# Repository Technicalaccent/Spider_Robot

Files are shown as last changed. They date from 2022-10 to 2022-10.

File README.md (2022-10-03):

# Spider Robot Master

What Is a "Spider Robot?"

	As its name defines it, our robot is a basic representation of the sipder movements but it will not perform exactly the same body moves since we are using only four legs instead of eight legs.

	Named also a Quadrupedrobot since it has four legs and make its movements using these legs, the movment of each leg is related to the other legs in order to identify the roboty body postion and also to control the robot body balance.

	Legged robots handle terrain better than their wheeled counterparts and move in varied and animalistic ways. However, this makes legged robots more complicated, and less accessible to many makers. and also the making cost and the high depenses that a maker should spend in order to create a full body quadruped since it is based on servo motors or stepper motors and both are more expensive than DC motors that could be used in wheeled robots.

Advantages

	You will find quadrupeds abundant in nature, because four legs allow for passive stability, or the ability to stay standing without actively adjusting position. The same is true of robots. A four-legged robot is cheaper and simpler than a robot with more legs, yet it can still achieve stability.

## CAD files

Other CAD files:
SpiderRobot master/3D parts/spider_robot.skp

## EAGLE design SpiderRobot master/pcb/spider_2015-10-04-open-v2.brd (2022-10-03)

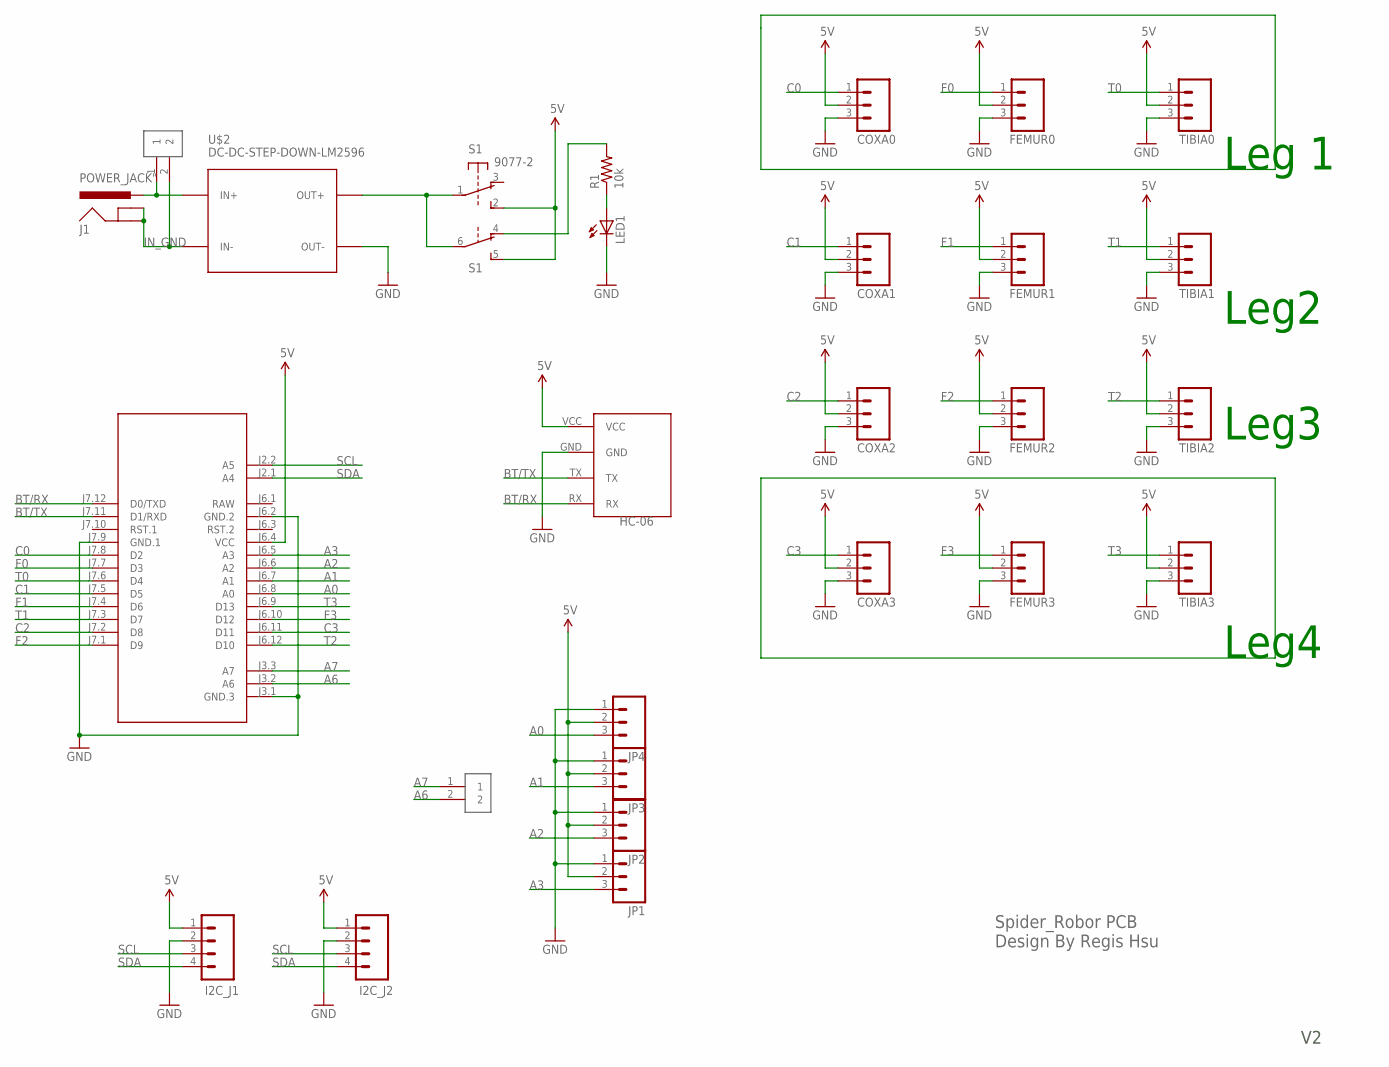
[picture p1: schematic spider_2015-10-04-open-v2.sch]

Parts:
COXA0, COXA1, COXA2, COXA3: M03PTH; 1X03
FEMUR0, FEMUR1, FEMUR2, FEMUR3: M03PTH; 1X03
HC-06: BLUETOOTH_BOARDSTANDING; BT_BOARD_FOOTPRINT_STANDING
I2C_J1, I2C_J2: 1X04_HEADER"; 1X04_HEADER
J1: POWER_JACK"; POWER_JACK
JP1, JP2, JP3, JP4: M03PTH; 1X03
LED1: LED3MM; LED
M1: ARDUINO-PRO-MINI-5.0V; ARDUINO-PRO-MINI
R1: 10k; AXIAL-0.4
S1: 9077-2
TIBIA0, TIBIA1, TIBIA2, TIBIA3: M03PTH; 1X03
U$1, U$3: 1X02_HEADER
U$2: DC-DC-STEP-DOWN-LM2596

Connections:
5V: COXA0.2, COXA1.2, COXA2.2, COXA3.2, FEMUR0.2, FEMUR1.2, FEMUR2.2, FEMUR3.2, HC-06.VCC, I2C_J1.1, I2C_J2.1, JP1.2, JP2.2, JP3.2, JP4.2, M1.J6.4 (VCC), S1.2 (S), S1.5 (S), TIBIA0.2, TIBIA1.2, TIBIA2.2, TIBIA3.2
A0: JP4.3, M1.J6.8 (A0)
A1: JP3.3, M1.J6.7 (A1)
A2: JP2.3, M1.J6.6 (A2)
A3: JP1.3, M1.J6.5 (A3)
A6: M1.J3.2 (A6), U$1.2
A7: M1.J3.3 (A7), U$1.1
BT/RX: HC-06.RX, M1.J7.12 (D0/TXD)
BT/TX: HC-06.TX, M1.J7.11 (D1/RXD)
C0: COXA0.1, M1.J7.8 (D2)
C1: COXA1.1, M1.J7.5 (D5)
C2: COXA2.1, M1.J7.2 (D8)
C3: COXA3.1, M1.J6.11 (D11)
F0: FEMUR0.1, M1.J7.7 (D3)
F1: FEMUR1.1, M1.J7.4 (D6)
F2: FEMUR2.1, M1.J7.1 (D9)
F3: FEMUR3.1, M1.J6.10 (D12)
GND: COXA0.3, COXA1.3, COXA2.3, COXA3.3, FEMUR0.3, FEMUR1.3, FEMUR2.3, FEMUR3.3, HC-06.GND, I2C_J1.2, I2C_J2.2, JP1.1, JP2.1, JP3.1, JP4.1, LED1.K (C), M1.J3.1 (GND.3), M1.J6.2 (GND.2), M1.J7.9 (GND.1), TIBIA0.3, TIBIA1.3, TIBIA2.3, TIBIA3.3, U$2.OUT-
IN_GND: J1.GND, J1.GNDBREAK, U$2.IN-, U$3.2
unnamed: J1.PWR, U$2.IN+, U$3.1
unnamed: S1.1, S1.6, U$2.OUT+
unnamed: R1.P$2 (2), S1.4 (O)
unnamed: LED1.A, R1.P$1 (1)
RAW: M1.J6.1 (RAW)
SCL: I2C_J1.3, I2C_J2.3, M1.J2.2 (A5)
SDA: I2C_J1.4, I2C_J2.4, M1.J2.1 (A4)
T0: M1.J7.6 (D4), TIBIA0.1
T1: M1.J7.3 (D7), TIBIA1.1
T2: M1.J6.12 (D10), TIBIA2.1
T3: M1.J6.9 (D13), TIBIA3.1

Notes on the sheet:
Spider_Robor PCB Design By Regis Hsu
Leg 1
Leg4
Leg3
Leg2

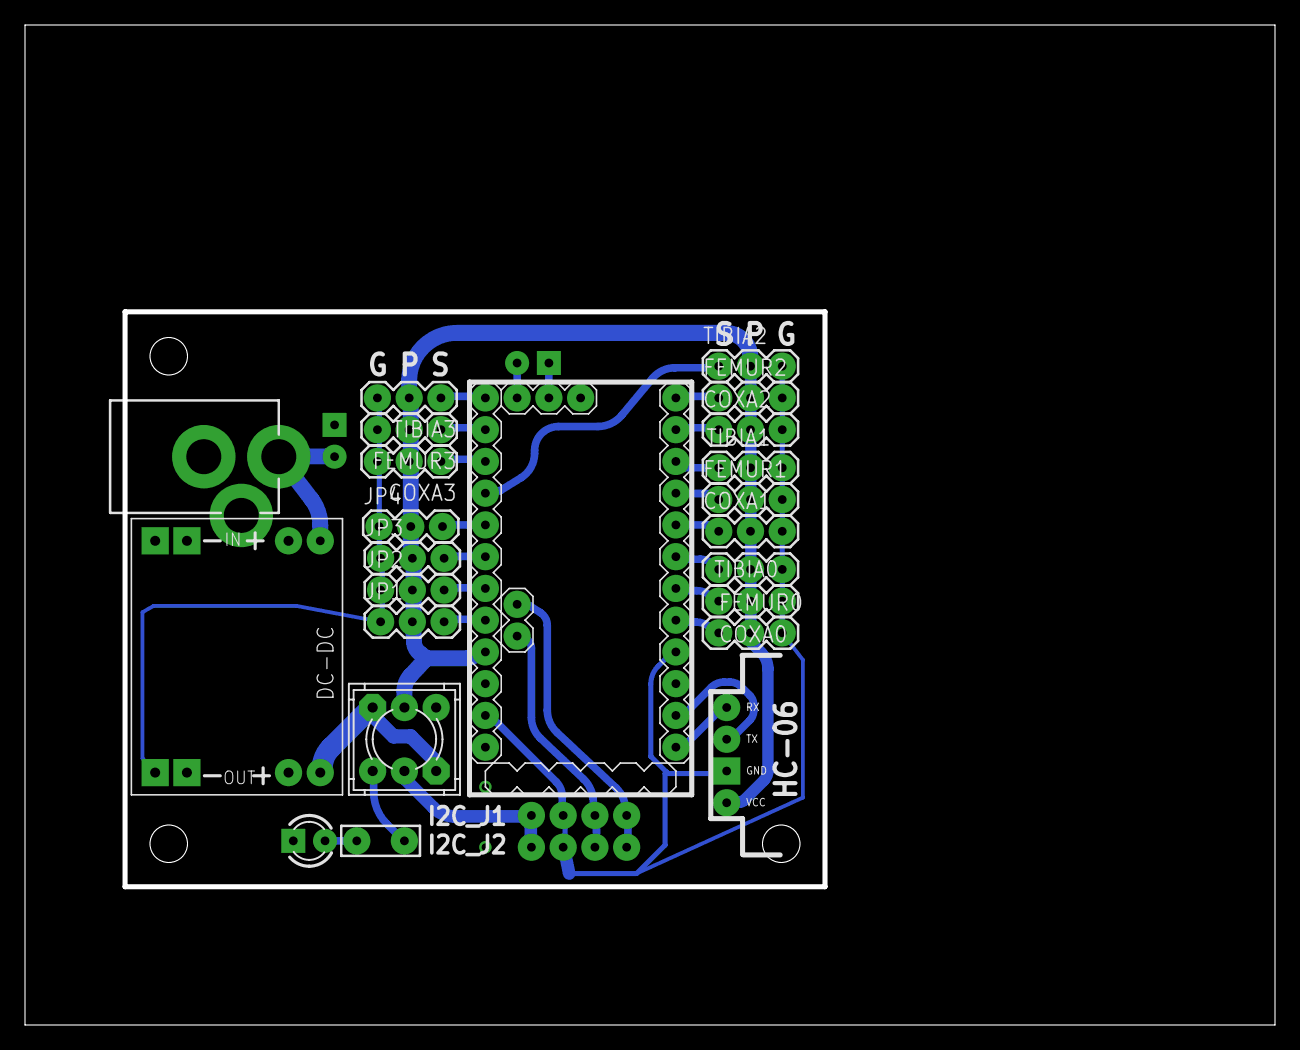
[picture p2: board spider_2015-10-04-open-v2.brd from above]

Board: 2 copper layers, 100.0 x 80.0 mm, 27 parts (0 on the bottom side), 29 nets.

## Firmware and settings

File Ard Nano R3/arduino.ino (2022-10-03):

/************************************************************************************************************************************************************************                                              

Spider Robot

***********************************************************************************************************************************************************************/

#include <Servo.h>    //to define and control servos
#include <FlexiTimer2.h>//to set a timer to manage all servos
#include <Wire.h>
#include <Adafruit_SSD1306.h>
#include <Adafruit_GFX.h>

// OLED display TWI address
#define OLED_ADDR   0x3C
Adafruit_SSD1306 display(-1);
/* Servos --------------------------------------------------------------------*/
//define 12 servos for 4 legs
Servo servo[4][3];
//define servos' ports
const int servo_pin[4][3] = { {11, 12, 13}, {2, 4, 7}, {14, 15, 16},{8, 9, 10} };/* Size of the robot ---------------------------------------------------------*/
const float length_a = 50;
const float length_b = 77.1;
const float length_c = 27.5;
const float length_side = 71;
const float z_absolute = -28;
/* Constants for movement ----------------------------------------------------*/
const float z_default = -50, z_up = -30, z_boot = z_absolute;
const float x_default = 62, x_offset = 0;
const float y_start = 0, y_step = 40;
const float y_default = x_default;
/* variables for movement ----------------------------------------------------*/
volatile float site_now[4][3];    //real-time coordinates of the end of each leg
volatile float site_expect[4][3]; //expected coordinates of the end of each leg
float temp_speed[4][3];   //each axis' speed, needs to be recalculated before each movement
float move_speed;     //movement speed
float speed_multiple = 1; //movement speed multiple
const float spot_turn_speed = 4;
const float leg_move_speed = 8;
const float body_move_speed = 3;
const float stand_seat_speed = 1;
volatile int rest_counter;      //+1/0.02s, for automatic rest
//functions' parameter
const float KEEP = 255;
//define PI for calculation
const float pi = 3.1415926;
/* Constants for turn --------------------------------------------------------*/
//temp length
const float temp_a = sqrt(pow(2 * x_default + length_side, 2) + pow(y_step, 2));
const float temp_b = 2 * (y_start + y_step) + length_side;
const float temp_c = sqrt(pow(2 * x_default + length_side, 2) + pow(2 * y_start + y_step + length_side, 2));
const float temp_alpha = acos((pow(temp_a, 2) + pow(temp_b, 2) - pow(temp_c, 2)) / 2 / temp_a / temp_b);
//site for turn
const float turn_x1 = (temp_a - length_side) / 2;
const float turn_y1 = y_start + y_step / 2;
const float turn_x0 = turn_x1 - temp_b * cos(temp_alpha);
const float turn_y0 = temp_b * sin(temp_alpha) - turn_y1 - length_side;

const int lightR=3;
const int lightG=5;
const int lightB=6;

int LedR=0;
int LedG=0;
int LedB=0;

char SerialData;                                    // Use this variable to read each caractere received through serial port
String data="";
void setup() 
{
  Serial.begin(9600);
  display.begin(SSD1306_SWITCHCAPVCC, OLED_ADDR);
  display.clearDisplay();
  display.display();
  delay(10000);
  set_site(0, x_default - x_offset, y_start + y_step, z_boot);
  set_site(1, x_default - x_offset, y_start + y_step, z_boot);
  set_site(2, x_default + x_offset, y_start, z_boot);
  set_site(3, x_default + x_offset, y_start, z_boot);
  for (int i = 0; i < 4; i++)
  {
    for (int j = 0; j < 3; j++)
    {
      site_now[i][j] = site_expect[i][j];
    }
  }
  //start servo service
  FlexiTimer2::set(20, servo_service);
  FlexiTimer2::start();
  //initialize servos
  servo_attach();
  stand();
//  delay(3000);
//  sit();
//  delay(3000);
//  stand();
//  delay(3000);
  happy();
  delay (random (500, 1000));
  cierra();
  delay (150);
  enfado();
  delay (random (1000, 3000));
  cierra();
  delay (150);
  entorna();
  delay (random (1000, 3000));
  cierra();
  delay (150);
  enfado1();
  delay (random (1000, 3000));
  cierra();
  delay (150);
  triste();
  delay (random (1000, 3000));
  cierra();
  delay (150);
  abre();
  delay (random (500, 3000));
  cierra();
  delay (150);
  happy();
  delay (random (500, 1000));
}

void loop() 
{
  while(Serial.available())                   // While serial data are available we store it 
  {
    delay(10);
    SerialData=Serial.read();
    if(SerialData=='b')
    LedR=Serial.parseInt();
    else if(SerialData=='g')
    LedG=Serial.parseInt();
    else if(SerialData=='r')
    LedB=Serial.parseInt();
    else
    data+=SerialData;
  }
  if(data=="f")                                  // If the stored data is forward movement
  {
    cierra();
    delay (150);
    happy();
    step_forward(1);
  }

  if(data=="p")                                  // If the stored data is backward movement
  {
    cierra();
    delay (150);
    triste();
    step_back(1);
  }

  if(data=="l")                                  // If the stored data is to turn left the car 
  {
    cierra();
    delay (150);
    enfado1();
    turn_left(1);
  }

  if(data=="m")                                  // If the stored data is to turn right the car
  {
    cierra();
    delay (150);
    enfado();
    turn_right(5);
  }
  data="";
  analogWrite(lightR,LedR);
  analogWrite(lightG,LedG);
  analogWrite(lightB,LedB);
}
void servo_attach(void)
{
  for (int i = 0; i < 4; i++)
  {
    for (int j = 0; j < 3; j++)
    {
      servo[i][j].attach(servo_pin[i][j]);
      delay(100);
    }
  }
}

void servo_detach(void)
{
  for (int i = 0; i < 4; i++)
  {
    for (int j = 0; j < 3; j++)
    {
      servo[i][j].detach();
      delay(100);
    }
  }
}

void sit(void)
{
  move_speed = stand_seat_speed;
  for (int leg = 0; leg < 4; leg++)
  {
    set_site(leg, KEEP, KEEP, z_boot);
  }
  wait_all_reach();
}

/*
  - stand
  - blocking function
   ---------------------------------------------------------------------------*/
void stand(void)
{
  move_speed = stand_seat_speed;
  for (int leg = 0; leg < 4; leg++)
  {
    set_site(leg, KEEP, KEEP, z_default);
  }
  wait_all_reach();
}


/*
  - spot turn to left
  - blocking function
  - parameter step steps wanted to turn
   ---------------------------------------------------------------------------*/
void turn_left(unsigned int step)
{
  move_speed = spot_turn_speed;
  while (step-- > 0)
  {
    if (site_now[3][1] == y_start)
    {
      //leg 3&1 move
      set_site(3, x_default + x_offset, y_start, z_up);
      wait_all_reach();

      set_site(0, turn_x1 - x_offset, turn_y1, z_default);
      set_site(1, turn_x0 - x_offset, turn_y0, z_default);
      set_site(2, turn_x1 + x_offset, turn_y1, z_default);
      set_site(3, turn_x0 + x_offset, turn_y0, z_up);
      wait_all_reach();

      set_site(3, turn_x0 + x_offset, turn_y0, z_default);
      wait_all_reach();

      set_site(0, turn_x1 + x_offset, turn_y1, z_default);
      set_site(1, turn_x0 + x_offset, turn_y0, z_default);
      set_site(2, turn_x1 - x_offset, turn_y1, z_default);
      set_site(3, turn_x0 - x_offset, turn_y0, z_default);
      wait_all_reach();

      set_site(1, turn_x0 + x_offset, turn_y0, z_up);
      wait_all_reach();

      set_site(0, x_default + x_offset, y_start, z_default);
      set_site(1, x_default + x_offset, y_start, z_up);
      set_site(2, x_default - x_offset, y_start + y_step, z_default);
      set_site(3, x_default - x_offset, y_start + y_step, z_default);
      wait_all_reach();

      set_site(1, x_default + x_offset, y_start, z_default);
      wait_all_reach();
    }
    else
    {
      //leg 0&2 move
      set_site(0, x_default + x_offset, y_start, z_up);
      wait_all_reach();

      set_site(0, turn_x0 + x_offset, turn_y0, z_up);
      set_site(1, turn_x1 + x_offset, turn_y1, z_default);
      set_site(2, turn_x0 - x_offset, turn_y0, z_default);
      set_site(3, turn_x1 - x_offset, turn_y1, z_default);
      wait_all_reach();

      set_site(0, turn_x0 + x_offset, turn_y0, z_default);
      wait_all_reach();

      set_site(0, turn_x0 - x_offset, turn_y0, z_default);
      set_site(1, turn_x1 - x_offset, turn_y1, z_default);
      set_site(2, turn_x0 + x_offset, turn_y0, z_default);
      set_site(3, turn_x1 + x_offset, turn_y1, z_default);
      wait_all_reach();

      set_site(2, turn_x0 + x_offset, turn_y0, z_up);
      wait_all_reach();

      set_site(0, x_default - x_offset, y_start + y_step, z_default);
      set_site(1, x_default - x_offset, y_start + y_step, z_default);
      set_site(2, x_default + x_offset, y_start, z_up);
      set_site(3, x_default + x_offset, y_start, z_default);
      wait_all_reach();

      set_site(2, x_default + x_offset, y_start, z_default);
      wait_all_reach();
    }
  }
}

/*
  - spot turn to right
  - blocking function
  - parameter step steps wanted to turn
   ---------------------------------------------------------------------------*/
void turn_right(unsigned int step)
{
  move_speed = spot_turn_speed;
  while (step-- > 0)
  {
    if (site_now[2][1] == y_start)
    {
      //leg 2&0 move
      set_site(2, x_default + x_offset, y_start, z_up);
      wait_all_reach();

      set_site(0, turn_x0 - x_offset, turn_y0, z_default);
      set_site(1, turn_x1 - x_offset, turn_y1, z_default);
      set_site(2, turn_x0 + x_offset, turn_y0, z_up);
      set_site(3, turn_x1 + x_offset, turn_y1, z_default);
      wait_all_reach();

      set_site(2, turn_x0 + x_offset, turn_y0, z_default);
      wait_all_reach();

      set_site(0, turn_x0 + x_offset, turn_y0, z_default);
      set_site(1, turn_x1 + x_offset, turn_y1, z_default);
      set_site(2, turn_x0 - x_offset, turn_y0, z_default);
      set_site(3, turn_x1 - x_offset, turn_y1, z_default);
      wait_all_reach();

      set_site(0, turn_x0 + x_offset, turn_y0, z_up);
      wait_all_reach();

      set_site(0, x_default + x_offset, y_start, z_up);
      set_site(1, x_default + x_offset, y_start, z_default);
      set_site(2, x_default - x_offset, y_start + y_step, z_default);
      set_site(3, x_default - x_offset, y_start + y_step, z_default);
      wait_all_reach();

      set_site(0, x_default + x_offset, y_start, z_default);
      wait_all_reach();
    }
    else
    {
      //leg 1&3 move
      set_site(1, x_default + x_offset, y_start, z_up);
      wait_all_reach();

      set_site(0, turn_x1 + x_offset, turn_y1, z_default);
      set_site(1, turn_x0 + x_offset, turn_y0, z_up);
      set_site(2, turn_x1 - x_offset, turn_y1, z_default);
      set_site(3, turn_x0 - x_offset, turn_y0, z_default);
      wait_all_reach();

      set_site(1, turn_x0 + x_offset, turn_y0, z_default);
      wait_all_reach();

      set_site(0, turn_x1 - x_offset, turn_y1, z_default);
      set_site(1, turn_x0 - x_offset, turn_y0, z_default);
      set_site(2, turn_x1 + x_offset, turn_y1, z_default);
      set_site(3, turn_x0 + x_offset, turn_y0, z_default);
      wait_all_reach();

      set_site(3, turn_x0 + x_offset, turn_y0, z_up);
      wait_all_reach();

      set_site(0, x_default - x_offset, y_start + y_step, z_default);
      set_site(1, x_default - x_offset, y_start + y_step, z_default);
      set_site(2, x_default + x_offset, y_start, z_default);
      set_site(3, x_default + x_offset, y_start, z_up);
      wait_all_reach();

      set_site(3, x_default + x_offset, y_start, z_default);
      wait_all_reach();
    }
  }
}

/*
  - go forward
  - blocking function
  - parameter step steps wanted to go
   ---------------------------------------------------------------------------*/
void step_forward(unsigned int step)
{
  move_speed = leg_move_speed;
  while (step-- > 0)
  {
    if (site_now[2][1] == y_start)
    {
      //leg 2&1 move
      set_site(2, x_default + x_offset, y_start, z_up);
      wait_all_reach();
      set_site(2, x_default + x_offset, y_start + 2 * y_step, z_up);
      wait_all_reach();
      set_site(2, x_default + x_offset, y_start + 2 * y_step, z_default);
      wait_all_reach();

      move_speed = body_move_speed;

      set_site(0, x_default + x_offset, y_start, z_default);
      set_site(1, x_default + x_offset, y_start + 2 * y_step, z_default);
      set_site(2, x_default - x_offset, y_start + y_step, z_default);
      set_site(3, x_default - x_offset, y_start + y_step, z_default);
      wait_all_reach();

      move_speed = leg_move_speed;

      set_site(1, x_default + x_offset, y_start + 2 * y_step, z_up);
      wait_all_reach();
      set_site(1, x_default + x_offset, y_start, z_up);
      wait_all_reach();
      set_site(1, x_default + x_offset, y_start, z_default);
      wait_all_reach();
    }
    else
    {
      //leg 0&3 move
      set_site(0, x_default + x_offset, y_start, z_up);
      wait_all_reach();
      set_site(0, x_default + x_offset, y_start + 2 * y_step, z_up);
      wait_all_reach();
      set_site(0, x_default + x_offset, y_start + 2 * y_step, z_default);
      wait_all_reach();

      move_speed = body_move_speed;

      set_site(0, x_default - x_offset, y_start + y_step, z_default);
      set_site(1, x_default - x_offset, y_start + y_step, z_default);
      set_site(2, x_default + x_offset, y_start, z_default);
      set_site(3, x_default + x_offset, y_start + 2 * y_step, z_default);
      wait_all_reach();

      move_speed = leg_move_speed;

      set_site(3, x_default + x_offset, y_start + 2 * y_step, z_up);
      wait_all_reach();
      set_site(3, x_default + x_offset, y_start, z_up);
      wait_all_reach();
      set_site(3, x_default + x_offset, y_start, z_default);
      wait_all_reach();
    }
  }
}

/*
  - go back
  - blocking function
  - parameter step steps wanted to go
   ---------------------------------------------------------------------------*/
void step_back(unsigned int step)
{
  move_speed = leg_move_speed;
  while (step-- > 0)
  {
    if (site_now[3][1] == y_start)
    {
      //leg 3&0 move
      set_site(3, x_default + x_offset, y_start, z_up);
      wait_all_reach();
      set_site(3, x_default + x_offset, y_start + 2 * y_step, z_up);
      wait_all_reach();
      set_site(3, x_default + x_offset, y_start + 2 * y_step, z_default);
      wait_all_reach();

      move_speed = body_move_speed;

      set_site(0, x_default + x_offset, y_start + 2 * y_step, z_default);
      set_site(1, x_default + x_offset, y_start, z_default);
      set_site(2, x_default - x_offset, y_start + y_step, z_default);
      set_site(3, x_default - x_offset, y_start + y_step, z_default);
      wait_all_reach();

      move_speed = leg_move_speed;

      set_site(0, x_default + x_offset, y_start + 2 * y_step, z_up);
      wait_all_reach();
      set_site(0, x_default + x_offset, y_start, z_up);
      wait_all_reach();
      set_site(0, x_default + x_offset, y_start, z_default);
      wait_all_reach();
    }
    else
    {
      //leg 1&2 move
      set_site(1, x_default + x_offset, y_start, z_up);
      wait_all_reach();
      set_site(1, x_default + x_offset, y_start + 2 * y_step, z_up);
      wait_all_reach();
      set_site(1, x_default + x_offset, y_start + 2 * y_step, z_default);
      wait_all_reach();

      move_speed = body_move_speed;

      set_site(0, x_default - x_offset, y_start + y_step, z_default);
      set_site(1, x_default - x_offset, y_start + y_step, z_default);
      set_site(2, x_default + x_offset, y_start + 2 * y_step, z_default);
      set_site(3, x_default + x_offset, y_start, z_default);
      wait_all_reach();

      move_speed = leg_move_speed;

      set_site(2, x_default + x_offset, y_start + 2 * y_step, z_up);
      wait_all_reach();
      set_site(2, x_default + x_offset, y_start, z_up);
      wait_all_reach();
      set_site(2, x_default + x_offset, y_start, z_default);
      wait_all_reach();
    }
  }
}

// add by RegisHsu

void body_left(int i)
{
  set_site(0, site_now[0][0] + i, KEEP, KEEP);
  set_site(1, site_now[1][0] + i, KEEP, KEEP);
  set_site(2, site_now[2][0] - i, KEEP, KEEP);
  set_site(3, site_now[3][0] - i, KEEP, KEEP);
  wait_all_reach();
}

void body_right(int i)
{
  set_site(0, site_now[0][0] - i, KEEP, KEEP);
  set_site(1, site_now[1][0] - i, KEEP, KEEP);
  set_site(2, site_now[2][0] + i, KEEP, KEEP);
  set_site(3, site_now[3][0] + i, KEEP, KEEP);
  wait_all_reach();
}

void hand_wave(int i)
{
  float x_tmp;
  float y_tmp;
  float z_tmp;
  move_speed = 1;
  if (site_now[3][1] == y_start)
  {
    body_right(15);
    x_tmp = site_now[2][0];
    y_tmp = site_now[2][1];
    z_tmp = site_now[2][2];
    move_speed = body_move_speed;
    for (int j = 0; j < i; j++)
    {
      set_site(2, turn_x1, turn_y1, 50);
      wait_all_reach();
      set_site(2, turn_x0, turn_y0, 50);
      wait_all_reach();
    }
    set_site(2, x_tmp, y_tmp, z_tmp);
    wait_all_reach();
    move_speed = 1;
    body_left(15);
  }
  else
  {
    body_left(15);
    x_tmp = site_now[0][0];
    y_tmp = site_now[0][1];
    z_tmp = site_now[0][2];
    move_speed = body_move_speed;
    for (int j = 0; j < i; j++)
    {
      set_site(0, turn_x1, turn_y1, 50);
      wait_all_reach();
      set_site(0, turn_x0, turn_y0, 50);
      wait_all_reach();
    }
    set_site(0, x_tmp, y_tmp, z_tmp);
    wait_all_reach();
    move_speed = 1;
    body_right(15);
  }
}

void hand_shake(int i)
{
  float x_tmp;
  float y_tmp;
  float z_tmp;
  move_speed = 1;
  if (site_now[3][1] == y_start)
  {
    body_right(15);
    x_tmp = site_now[2][0];
    y_tmp = site_now[2][1];
    z_tmp = site_now[2][2];
    move_speed = body_move_speed;
    for (int j = 0; j < i; j++)
    {
      set_site(2, x_default - 30, y_start + 2 * y_step, 55);
      wait_all_reach();
      set_site(2, x_default - 30, y_start + 2 * y_step, 10);
      wait_all_reach();
    }
    set_site(2, x_tmp, y_tmp, z_tmp);
    wait_all_reach();
    move_speed = 1;
    body_left(15);
  }
  else
  {
    body_left(15);
    x_tmp = site_now[0][0];
    y_tmp = site_now[0][1];
    z_tmp = site_now[0][2];
    move_speed = body_move_speed;
    for (int j = 0; j < i; j++)
    {
      set_site(0, x_default - 30, y_start + 2 * y_step, 55);
      wait_all_reach();
      set_site(0, x_default - 30, y_start + 2 * y_step, 10);
      wait_all_reach();
    }
    set_site(0, x_tmp, y_tmp, z_tmp);
    wait_all_reach();
    move_speed = 1;
    body_right(15);
  }
}

void head_up(int i)
{
  set_site(0, KEEP, KEEP, site_now[0][2] - i);
  set_site(1, KEEP, KEEP, site_now[1][2] + i);
  set_site(2, KEEP, KEEP, site_now[2][2] - i);
  set_site(3, KEEP, KEEP, site_now[3][2] + i);
  wait_all_reach();
}

void head_down(int i)
{
  set_site(0, KEEP, KEEP, site_now[0][2] + i);
  set_site(1, KEEP, KEEP, site_now[1][2] - i);
  set_site(2, KEEP, KEEP, site_now[2][2] + i);
  set_site(3, KEEP, KEEP, site_now[3][2] - i);
  wait_all_reach();
}

//void body_dance(int i)
//{
//  float x_tmp;
//  float y_tmp;
//  float z_tmp;
//  float body_dance_speed = 2;
//  sit();
//  move_speed = 1;
//  set_site(0, x_default, y_default, KEEP);
//  set_site(1, x_default, y_default, KEEP);
//  set_site(2, x_default, y_default, KEEP);
//  set_site(3, x_default, y_default, KEEP);
//  wait_all_reach();
//  //stand();
//  set_site(0, x_default, y_default, z_default - 20);
//  set_site(1, x_default, y_default, z_default - 20);
//  set_site(2, x_default, y_default, z_default - 20);
//  set_site(3, x_default, y_default, z_default - 20);
//  wait_all_reach();
//  move_speed = body_dance_speed;
//  head_up(30);
//  for (int j = 0; j < i; j++)
//  {
//    if (j > i / 4)
//      move_speed = body_dance_speed * 2;
//    if (j > i / 2)
//      move_speed = body_dance_speed * 3;
//    set_site(0, KEEP, y_default - 20, KEEP);
//    set_site(1, KEEP, y_default + 20, KEEP);
//    set_site(2, KEEP, y_default - 20, KEEP);
//    set_site(3, KEEP, y_default + 20, KEEP);
//    wait_all_reach();
//    set_site(0, KEEP, y_default + 20, KEEP);
//    set_site(1, KEEP, y_default - 20, KEEP);
//    set_site(2, KEEP, y_default + 20, KEEP);
//    set_site(3, KEEP, y_default - 20, KEEP);
//    wait_all_reach();
//  }
//  move_speed = body_dance_speed;
//  head_down(30);
//}


/*
  - microservos service /timer interrupt function/50Hz
  - when set site expected,this function move the end point to it in a straight line
  - temp_speed[4][3] should be set before set expect site,it make sure the end point
   move in a straight line,and decide move speed.
   ---------------------------------------------------------------------------*/
void servo_service(void)
{
  sei();
  static float alpha, beta, gamma;

  for (int i = 0; i < 4; i++)
  {
    for (int j = 0; j < 3; j++)
    {
      if (abs(site_now[i][j] - site_expect[i][j]) >= abs(temp_speed[i][j]))
        site_now[i][j] += temp_speed[i][j];
      else
        site_now[i][j] = site_expect[i][j];
    }

    cartesian_to_polar(alpha, beta, gamma, site_now[i][0], site_now[i][1], site_now[i][2]);
    polar_to_servo(i, alpha, beta, gamma);
  }

  rest_counter++;
}

/*
  - set one of end points' expect site
  - this founction will set temp_speed[4][3] at same time
  - non - blocking function
   ---------------------------------------------------------------------------*/
void set_site(int leg, float x, float y, float z)
{
  float length_x = 0, length_y = 0, length_z = 0;

  if (x != KEEP)
    length_x = x - site_now[leg][0];
  if (y != KEEP)
    length_y = y - site_now[leg][1];
  if (z != KEEP)
    length_z = z - site_now[leg][2];

  float length = sqrt(pow(length_x, 2) + pow(length_y, 2) + pow(length_z, 2));

  temp_speed[leg][0] = length_x / length * move_speed * speed_multiple;
  temp_speed[leg][1] = length_y / length * move_speed * speed_multiple;
  temp_speed[leg][2] = length_z / length * move_speed * speed_multiple;

  if (x != KEEP)
    site_expect[leg][0] = x;
  if (y != KEEP)
    site_expect[leg][1] = y;
  if (z != KEEP)
    site_expect[leg][2] = z;
}
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
